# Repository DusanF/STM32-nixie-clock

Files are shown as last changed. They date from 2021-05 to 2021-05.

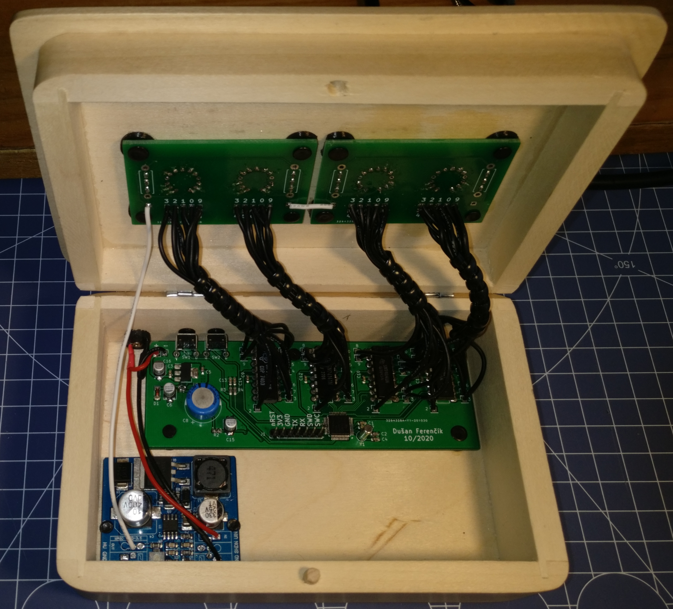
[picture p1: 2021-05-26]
photos/IMG_20210526_173008.jpg

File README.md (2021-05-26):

# STM32 nixie clock
My take on nixie tube clock, using STM32G070 with internal RTC and four 74141 as drivers.
Clock uses Czechoslovak ZM1082T, but main board can by used with any nixie tubes.

Clock

## Firmware
Folder Nixie_clock contains STM32CubeIDE project. Firmware is written in C using STM32 HAL libraries. After peripherals are initialized, main loop starts with 100ms period. After checking state of buttons and reading current time from RTC, displayed time is updated if needed. Once every minute, cathode poisoning prevention routine is started, cycling through every digit for a few milliseconds, before settling at current time.

## Schematic + PCB
Folder contains KiCad project with schematic and PCB design. Schematic is also exported in pdf format.

Device is powered by 12V DC. With all 4 digits lit up, current draw is about 150mA. HV for nixies is generated by external step-up module, that can be bought cheaply on ebay, aliexpress, etc. 74141s are powered by 5V generated by 1117. MCU gets 3.3V stabilised only by zener diode from 5V rail. Oprional supercap for RTC backup is charged by MCU via integrated resistor (set in FW to 1k5).

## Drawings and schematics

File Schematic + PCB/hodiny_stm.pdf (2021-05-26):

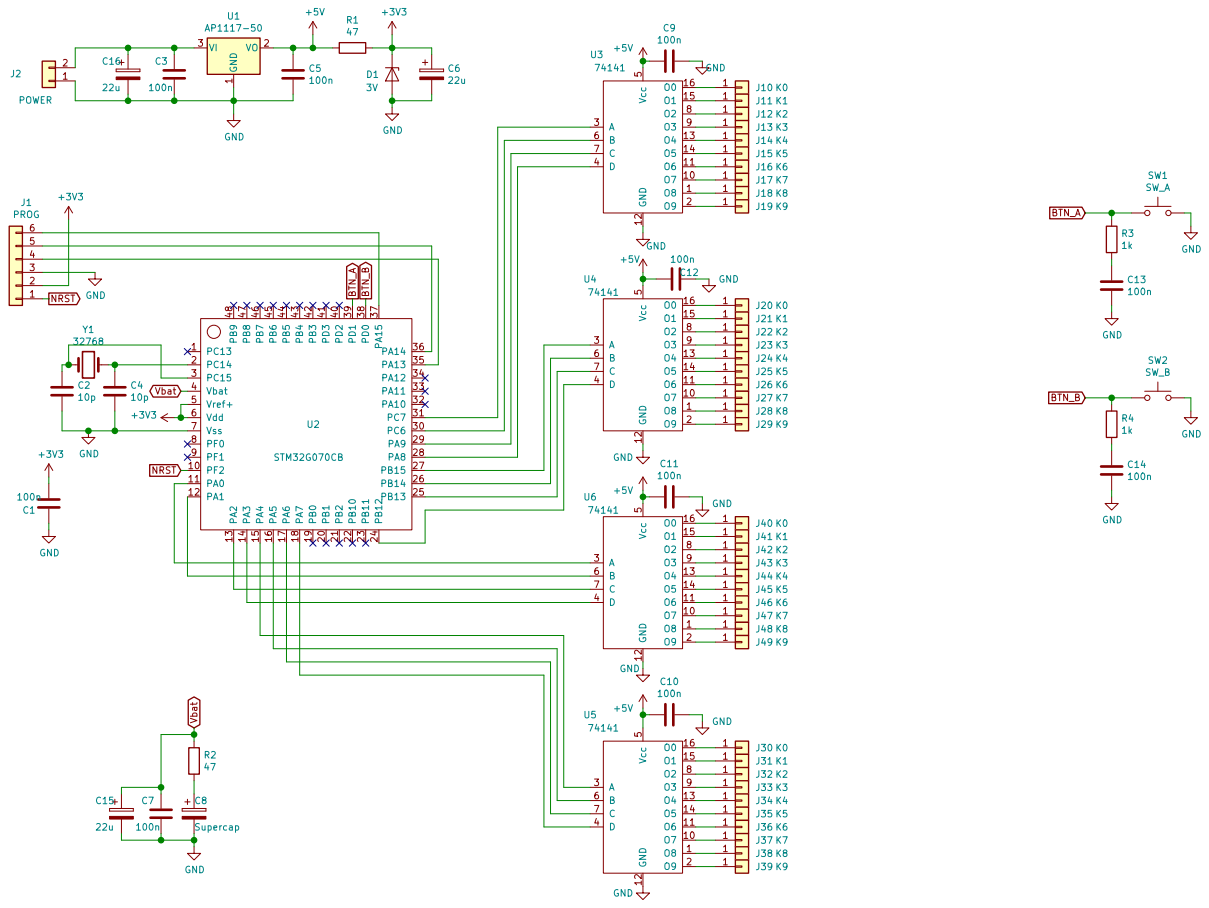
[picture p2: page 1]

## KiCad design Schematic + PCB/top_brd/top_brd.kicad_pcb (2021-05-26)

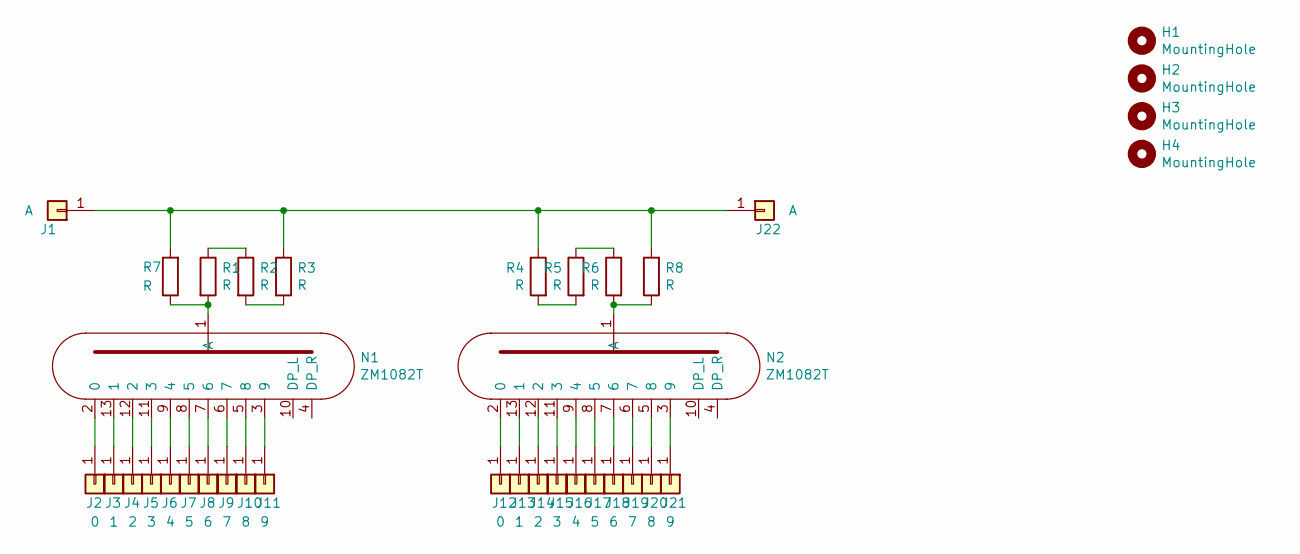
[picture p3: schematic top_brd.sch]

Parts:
H1, H2, H3, H4: MountingHole; MountingHole_3.2mm_M3
J1, J22: A; PinSocket_1x01_P2.54mm_Vertical
J2, J12: 0; PinSocket_1x01_P2.54mm_Vertical
J3, J13: 1; PinSocket_1x01_P2.54mm_Vertical
J4, J14: 2; PinSocket_1x01_P2.54mm_Vertical
J5, J15: 3; PinSocket_1x01_P2.54mm_Vertical
J6, J16: 4; PinSocket_1x01_P2.54mm_Vertical
J7, J17: 5; PinSocket_1x01_P2.54mm_Vertical
J8, J18: 6; PinSocket_1x01_P2.54mm_Vertical
J9, J19: 7; PinSocket_1x01_P2.54mm_Vertical
J10, J20: 8; PinSocket_1x01_P2.54mm_Vertical
J11, J21: 9; PinSocket_1x01_P2.54mm_Vertical
N1, N2: ZM1082T; CPA_14
R1, R2, R3, R4, R5, R6: R; R_0603_1608Metric
R7, R8: R; R_Axial_DIN0411_L9.9mm_D3.6mm_P12.70mm_Horizontal

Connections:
unnamed: J1.1, J22.1, R3.1, R4.1, R7.2, R8.2
unnamed: J2.1, N1.2 (0)
unnamed: J3.1, N1.13 (1)
unnamed: J4.1, N1.12 (2)
unnamed: J5.1, N1.11 (3)
unnamed: J6.1, N1.9 (4)
unnamed: J7.1, N1.8 (5)
unnamed: J8.1, N1.7 (6)
unnamed: J9.1, N1.6 (7)
unnamed: J10.1, N1.5 (8)
unnamed: J11.1, N1.3 (9)
unnamed: J12.1, N2.2 (0)
unnamed: J13.1, N2.13 (1)
unnamed: J14.1, N2.12 (2)
unnamed: J15.1, N2.11 (3)
unnamed: J16.1, N2.9 (4)
unnamed: J17.1, N2.8 (5)
unnamed: J18.1, N2.7 (6)
unnamed: J19.1, N2.6 (7)
unnamed: J20.1, N2.5 (8)
unnamed: J21.1, N2.3 (9)
unnamed: N1.1 (A), R1.2, R7.1
unnamed: N2.1 (A), R6.2, R8.1
unnamed: R1.1, R2.1
unnamed: R2.2, R3.2
unnamed: R4.2, R5.2
unnamed: R5.1, R6.1

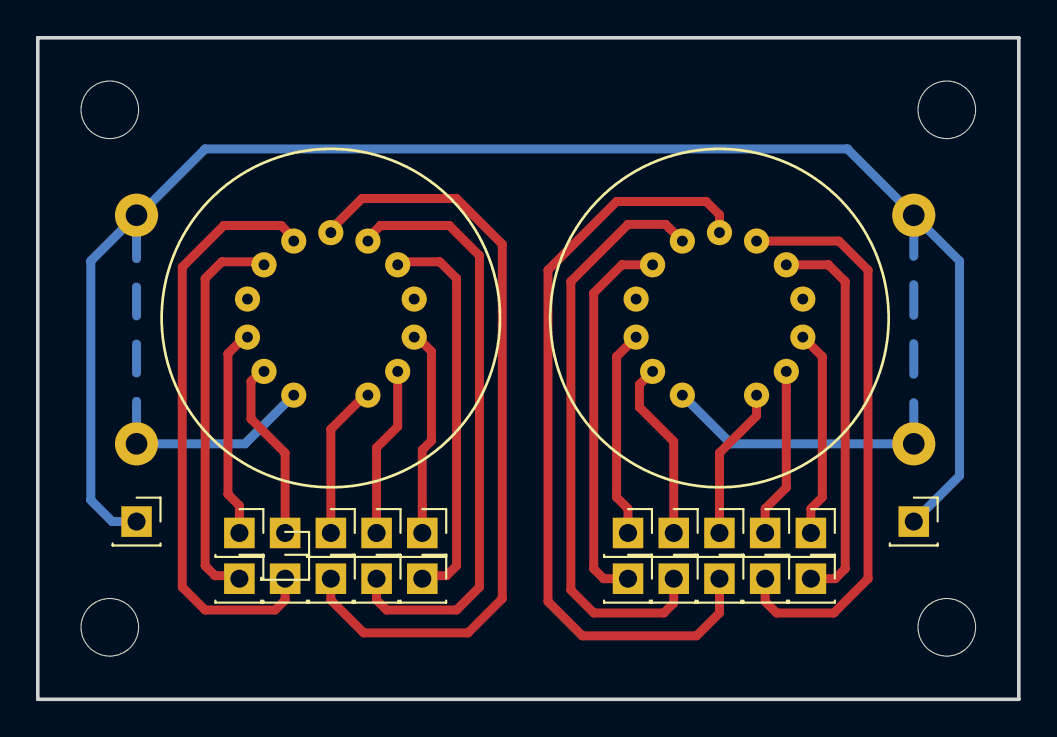
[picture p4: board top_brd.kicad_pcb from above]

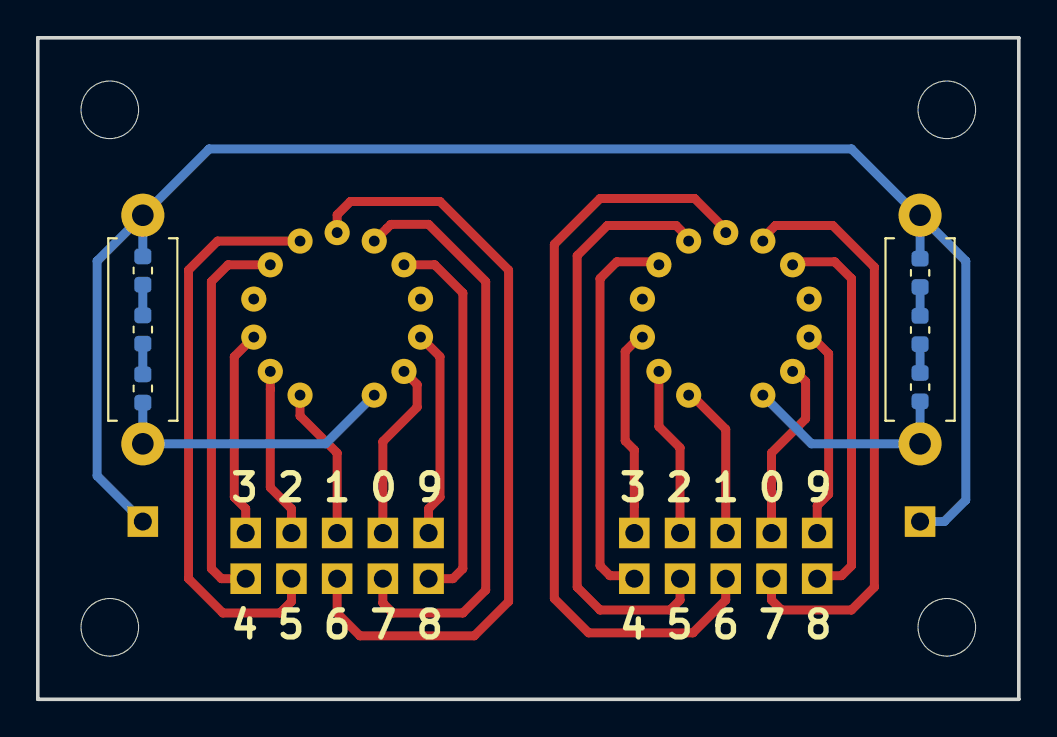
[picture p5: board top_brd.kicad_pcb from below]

Board: 2 copper layers, 54.5 x 36.8 mm, 36 parts (8 on the bottom side), 27 nets.

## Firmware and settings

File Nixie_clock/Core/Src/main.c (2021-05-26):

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
/* Includes ------------------------------------------------------------------*/
#include "main.h"
#include "rtc.h"
#include "tim.h"
#include "gpio.h"

/* USER CODE BEGIN Includes */
#include <string.h>
#include "nixie.h"
/* USER CODE END Includes */


void SystemClock_Config(void);
/**
  * @brief  The application entry point.
  * @retval int
  */
int main(void)
{
  /* MCU Configuration--------------------------------------------------------*/

  /* Reset of all peripherals, Initializes the Flash interface and the Systick. */
  HAL_Init();

  /* Configure the system clock */
  SystemClock_Config();

  /* Initialize all configured peripherals */
  MX_GPIO_Init();
  MX_RTC_Init();
  /* USER CODE BEGIN 2 */

  HAL_PWREx_EnableBatteryCharging(PWR_BATTERY_CHARGING_RESISTOR_1_5);	//enable Vbat charging (1k5)
  HAL_RTCEx_SetSmoothCalib(&hrtc, RTC_SMOOTHCALIB_PERIOD_32SEC, RTC_SMOOTHCALIB_PLUSPULSES_RESET, 70);	//kalibracia rtc -66.8ppm
  	  	  	  	  	  	  	  	  //1+(-70/(2^20 +70))

  /* USER CODE END 2 */

  /* Infinite loop */
  /* USER CODE BEGIN WHILE */

  RTC_TimeTypeDef curr_time = {0};
  RTC_DateTypeDef curr_date = {0};
  uint8_t display[4];	//digits to display, >=10 = blank
  uint8_t display_old[4]={0};
  uint8_t old_mins=0, old_hours=0x25;	//force refresh

  uint8_t btn_a_cnt=0;
  uint8_t btn_b_cnt=0;

  for(uint8_t i=0; i<10; i++){	//briefly light up every digit
	  display[0] = i;
	  display[1] = i;
	  display[2] = i;
	  display[3] = i;
	  nixie_display(display);
	  HAL_Delay(150);
  }
  display[0] = 11;
  display[1] = 11;
  display[2] = 11;
  display[3] = 11;
  nixie_display(display);

  HAL_Delay(500);

  while (1)
  {
    /* USER CODE END WHILE */

    /* USER CODE BEGIN 3 */

	  if(HAL_GPIO_ReadPin(BTN_A_GPIO_Port, BTN_A_Pin))	//check buttons (active low)
		  btn_a_cnt=0;
	  else if(btn_a_cnt<6)	//count up to 6 (loop period = 100ms, long press if cnt>5 (500ms))
		  btn_a_cnt++;

	  if(HAL_GPIO_ReadPin(BTN_B_GPIO_Port, BTN_B_Pin))
		  btn_b_cnt=0;
	  else if(btn_b_cnt<6)
		  btn_b_cnt++;

	  HAL_RTC_GetTime(&hrtc, &curr_time, RTC_FORMAT_BCD);
	  HAL_RTC_GetDate(&hrtc, &curr_date, RTC_FORMAT_BCD);	//need to read date even when not used because of buffered registers



	  if(btn_b_cnt == 1 || btn_b_cnt == 6){		//ignore 2-5 to allow short press of button
		  curr_time.Minutes = RTC_ByteToBcd2((RTC_Bcd2ToByte(curr_time.Minutes) + 1) % 60);
		  curr_time.Seconds = 0;
		  HAL_RTC_SetTime(&hrtc, &curr_time, RTC_FORMAT_BCD);
	  }
	  if(btn_a_cnt == 1 || btn_a_cnt == 6){
		  curr_time.Hours = RTC_ByteToBcd2((RTC_Bcd2ToByte(curr_time.Hours) + 1) % 24);
		  curr_time.Seconds = 0;
		  HAL_RTC_SetTime(&hrtc, &curr_time, RTC_FORMAT_BCD);
	  }
#ifdef FORMAT_12H
	  curr_time.Hours = RTC_ByteToBcd2(((RTC_Bcd2ToByte(curr_time.Hours)) % 12) + 1);
#endif

	  if(old_mins != curr_time.Minutes || old_hours != curr_time.Hours){
		  display[0] = (curr_time.Hours & 0xF0) ? (curr_time.Hours >> 4) : (0xF);	//display only single digit of hours unless needed
		  display[1] = curr_time.Hours & 0xF;
		  display[2] = curr_time.Minutes >> 4;
		  display[3] = curr_time.Minutes & 0xF;

		  if(btn_a_cnt == 0 && btn_b_cnt == 0)	//if not setting time, do CPP - cathode poisoning prevention
			  nixie_cpp(display, display_old);

		  nixie_display(display);

		  memcpy(display_old, display, 4);
		  old_mins = curr_time.Minutes;
		  old_hours = curr_time.Hours;
	  }
	  HAL_Delay(100);
  }
  /* USER CODE END 3 */
}

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


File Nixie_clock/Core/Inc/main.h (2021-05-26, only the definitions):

#define NIX_4A_Pin GPIO_PIN_0
#define NIX_4A_GPIO_Port GPIOA
#define NIX_4B_Pin GPIO_PIN_1
#define NIX_4B_GPIO_Port GPIOA
#define NIX_4C_Pin GPIO_PIN_2
#define NIX_4C_GPIO_Port GPIOA
#define NIX_4D_Pin GPIO_PIN_3
#define NIX_4D_GPIO_Port GPIOA
#define NIX_3A_Pin GPIO_PIN_4
#define NIX_3A_GPIO_Port GPIOA
#define NIX_3B_Pin GPIO_PIN_5
#define NIX_3B_GPIO_Port GPIOA
#define NIX_3C_Pin GPIO_PIN_6
#define NIX_3C_GPIO_Port GPIOA
#define NIX_3D_Pin GPIO_PIN_7
#define NIX_3D_GPIO_Port GPIOA
#define NIX_2A_Pin GPIO_PIN_0
#define NIX_2A_GPIO_Port GPIOB
#define NIX_2B_Pin GPIO_PIN_1
#define NIX_2B_GPIO_Port GPIOB
#define NIX_2C_Pin GPIO_PIN_2
#define NIX_2C_GPIO_Port GPIOB
#define NIX_2D_Pin GPIO_PIN_12
#define NIX_2D_GPIO_Port GPIOB
#define NIX_1A_Pin GPIO_PIN_13
#define NIX_1A_GPIO_Port GPIOB
#define NIX_1B_Pin GPIO_PIN_14
#define NIX_1B_GPIO_Port GPIOB
#define NIX_1C_Pin GPIO_PIN_15
#define NIX_1C_GPIO_Port GPIOB
#define NIX_1D_Pin GPIO_PIN_8
#define NIX_1D_GPIO_Port GPIOA
#define BTN_B_Pin GPIO_PIN_0
#define BTN_B_GPIO_Port GPIOD
#define BTN_A_Pin GPIO_PIN_1
#define BTN_A_GPIO_Port GPIOD

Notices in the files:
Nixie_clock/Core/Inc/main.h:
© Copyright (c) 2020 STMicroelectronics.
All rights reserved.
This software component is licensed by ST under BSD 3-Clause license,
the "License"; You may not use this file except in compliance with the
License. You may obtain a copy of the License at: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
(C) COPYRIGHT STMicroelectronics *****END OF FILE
